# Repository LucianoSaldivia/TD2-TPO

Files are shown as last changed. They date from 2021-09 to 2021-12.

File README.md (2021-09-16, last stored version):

# TD2-TPO
 Proyecto Emulador de Chip8 para Técnicas Digitales 2

| Tarea | Responsable  | Estado |
|:---|:---:|:---:|
| Diseño PCB |  LL y Willy  | - |
| Diseño Carcaza | Fran | - |
| Pantalla | LL | - |
| SD | Luchos | - |
| Instrucciones | Fran, Luchos | + |
| Armado | LL | - |
| TDS y estructura | LS | T |
| Documentacion |  el guilardo | - |
| Interfaz seleccion juego | Luchos | - |

- Estados de Tareas:
  - "-"	-> Tarea en proceso
  - "+"	-> Tarea codeada, no testeada	
  - "T"	-> Tarea testeada, no integrada
  - "I"	-> Tarea integrada

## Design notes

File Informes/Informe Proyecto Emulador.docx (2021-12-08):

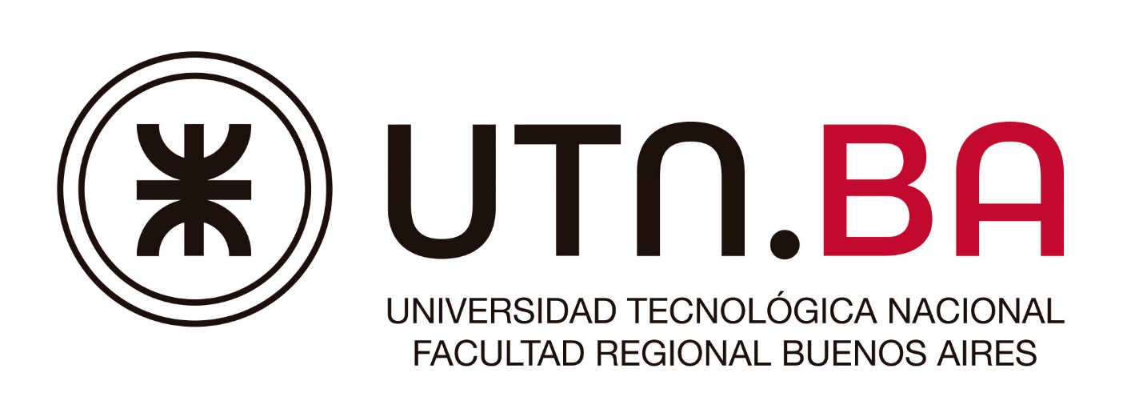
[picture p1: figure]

Técnicas Digitales II

Informe Técnico

Año 2021

Integrantes:

- Barreras Fauvety, Guillermo.

- Lopez, Luciano.

- Saldivia, Luciano.

- Stahl, Francisco.

Índice:

1. Descripción General.

1.1 Introducción.

1.2 Interfaz con el usuario.

1.3 Operación.

2. Hardware.

2.1 Diagrama en bloques.

2.2 Circuito esquemático.

2.3 Circuito Board.

2.4 Descripción del circuito.

2.5 Circuito impreso.

3. Software.

3.1 Entorno de desarrollo.

3.2 Sistema operativo.

3.3 Bibliotecas.

3.4 Programa principal.

3.5 Máquina de estados ¿?????

3.5 Rutinas de interrupción.

3.6 Rutinas generales.

4. Referencias.

1. Descripción General

1.1 Introducción

El proyecto trata sobre un emulador de chip 8. Es capaz de ejecutar ROMs desde una SD y ejecutarlas. Consta básicamente de dos dispositivos de entrada, una tarjeta SD por donde se cargarán las ROMs y un teclado matricial para ingresar los comandos por teclado, por último, un dispositivo de salida que será un display grafico monocromático de 128*64 pixeles.

Se emula el sistema completo, incluyendo stack pointer, registros de propósito general, memoria de video, memoria de teclado y set de instrucciones completo.

1.2 Interfaz con el usuario

El usuario tendrá como método de ingreso de información el teclado matricial, la bluepill será la encargada de interpretar qué teclas fueron presionadas y actuar en consecuencia. La presentación al usuario de la información procesada será a través del display hallado en la parte superior del dispositivo.

Además de las mencionadas interfaces, se encuentran en la parte inferior un switch de ON/OFF y un botón de reset.

1.3 Operación

La operación es sencilla, la interfaz de usuario también. A penas el equipo es alimentado, el directorio aparece en la pantalla. Con la tecla 2, el usuario recorrerá el directorio raíz y, por último, si quiere elegir una ROM simplemente debe oprimir el botón 5 y esperar a que la misma cargue. El dispositivo cuenta con un teclado matricial de 16 teclas (4x4) completamente funcionales mapeadas según la implementación original de chip 8. Las ROMs utilizan las teclas 2 (mover arriba), 4 (mover izquierda), 8 (mover abajo) y 6 (mover derecha) al igual que las flechas del teclado de la PC para jugar un juego).

2. Hardware

2.1 Diagrama en bloques

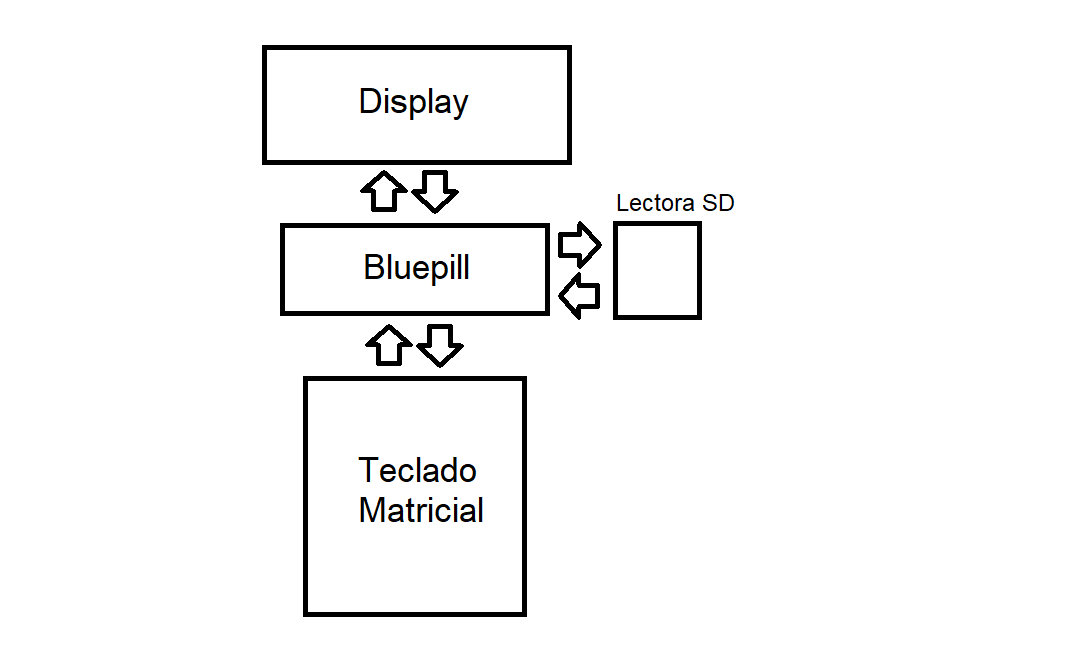
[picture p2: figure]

Tanto el display como la tarjeta SD utilizan el protocolo de comunicación SPI. El teclado matricial es controlado por una secuencia de barrido utilizando pines de propósito general.

2.2 Circuito esquemático

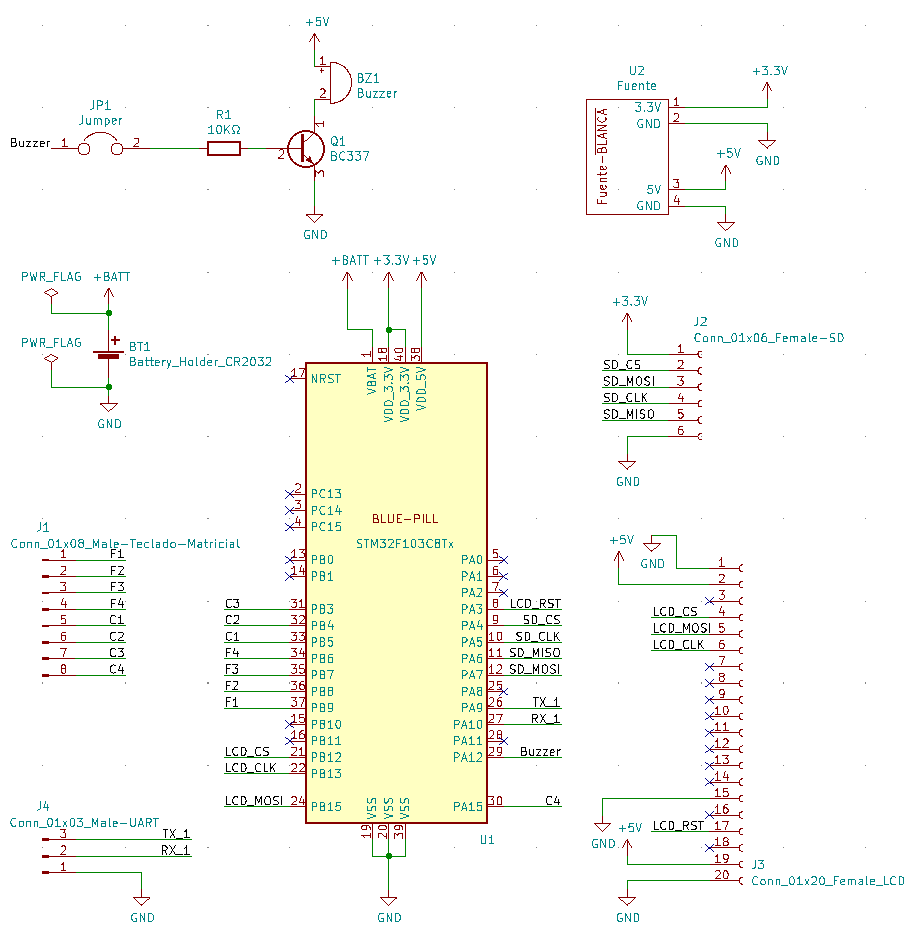
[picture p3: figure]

2.3 Circuito board

Sin plano de masa:

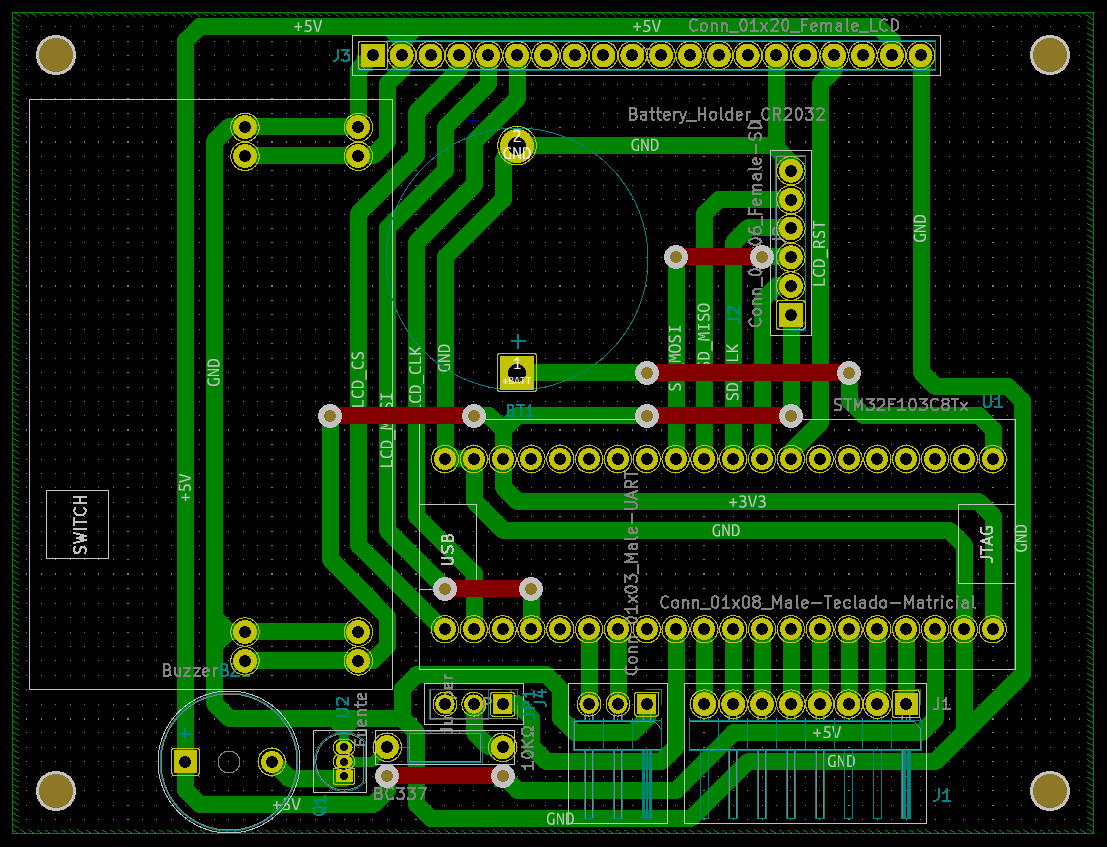
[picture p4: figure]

Con plano de masa:

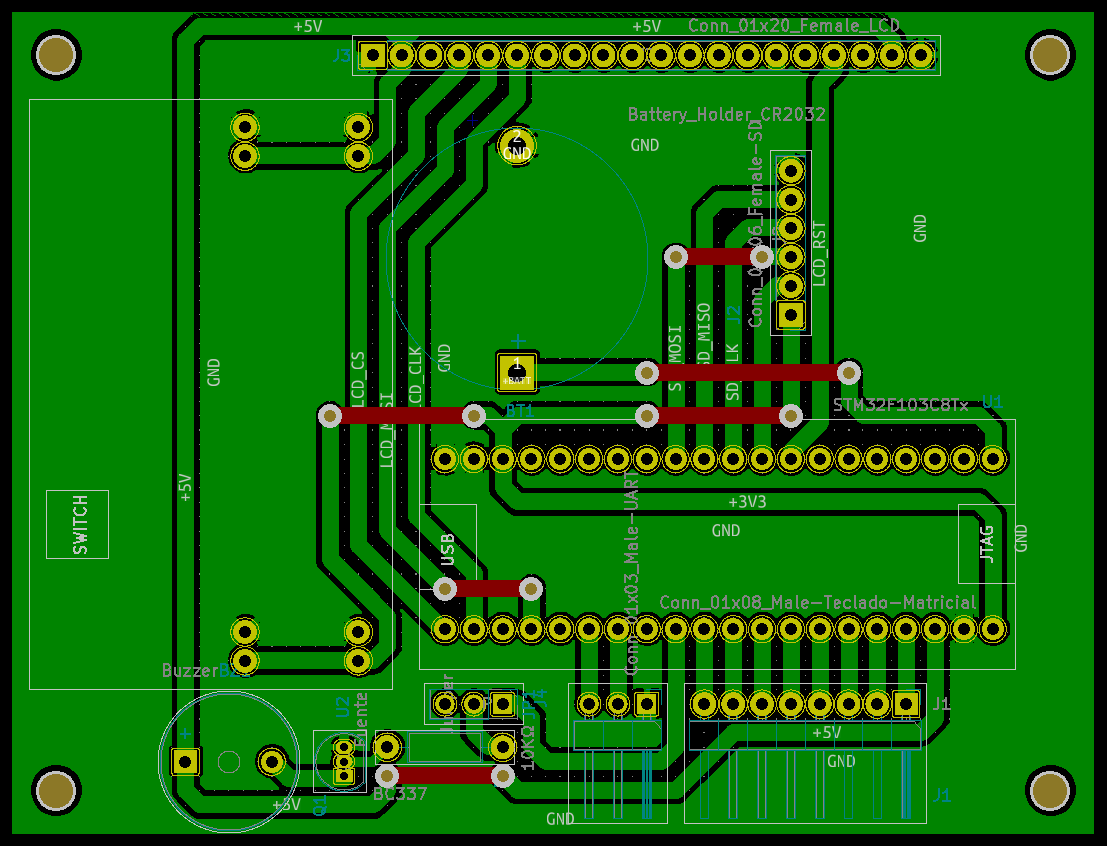
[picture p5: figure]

2.4 Descripción del circuito

El circuito consta de partes:

1. BLUEPILL: Microcontrolador principal.
2. Modulo SD: Placa secundaria conectada por una tira de pines a la placa principal.
3. PILA para RTC: Se utiliza para obtener un correcto funcionamiento de la librería FATFS al momento de escribir archivos para que luego tengan un correcto timestamp.
4. Conector teclado matricial y display: tira de pines hembra.
5. Regulador de tensión: Es la encargada de suministrar 5V y 3.3V para todos los componentes del proyecto.
6. Buzzer: Accionado a través de un transistor funcionando en conmutación, el mismo está configurado como emisor común. Se le colocó un jumper en serie con la resistencia de base para tener un mejor control del mismo y evitar sonidos molestos al momento de realizar pruebas.

2.5 Circuito impreso

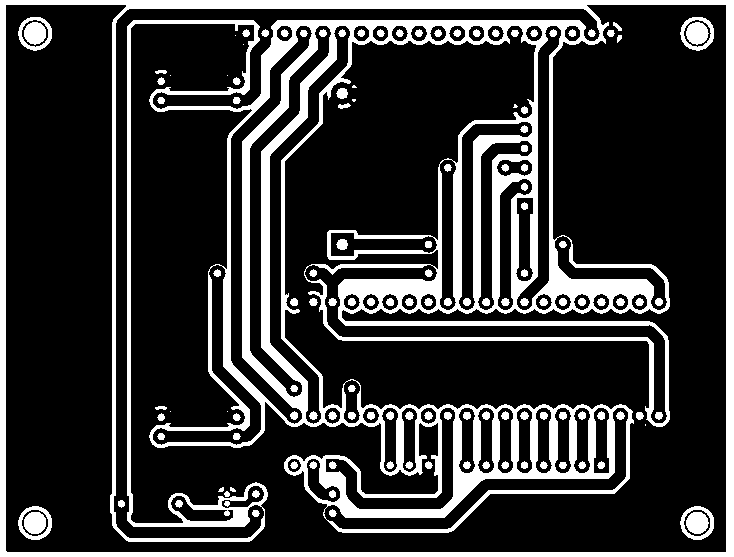
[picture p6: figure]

3. Software

3.1 Entorno de desarrollo: Se utilizo el IDE provisto por la catedra STM32Cube IDE. Para configurar el hardware se utilizó la herramienta de configuración de hardware para setear la mayoría de los periféricos.

3.2 Sistema operativo: Hay 3 tareas, de las cuales execute_instruction (wcet = 27 ms), es la que más carga impone al procesamiento del sistema, dado que, entre otras cosas, actualiza el display. Luego las otras tareas son actualizar_buzzer (wcet = 2 us) y process_user_input (wcet = 50 us).

Para hacer estas pruebas, se copiaron las tareas y se las adaptaron para ser incluidas en un scheduler, logrando así implementar la máquina de estado en un sistema TDS. Las primeras pruebas fueron hechas con un tick de sistema (o período secundario) de 10 ms, y era perceptible, en ciertos momentos, una falta de respuesta por parte del teclado (es decir que no se ejecutaba correctamente o a tiempo la tarea process_user_input), al tomar las entradas, en ciertas ocasiones se congelaba el display por un instante y luego continuaba, lo que mostraba que estábamos sobrecargando al scheduler con los tiempos de las tareas.

Repensando el análisis y las pruebas hechas, y conociendo el código, fue fácil darse cuenta de que el problema estaba en la variabilidad de la tarea execute_instruction, que, si bien en el peor caso tomaba unos 27 ms, la mayoría de las veces que esta tarea era ejecutada, el tiempo que tomaba era mucho menor, dado que solamente algunas veces la instrucción a ejecutar por el chip8 emulado era la de actualizar el display, y la mayoría de las veces eran instrucciones muchísimo más simples. Al haber medido esto, se observó que el tiempo de ejecución en cada tick (de los que vimos simulando) era de 1ms, 400 us, y lo más frecuente, menos de 20 us, pero la menos frecuente y más relevante era al actualizar el display. Por lo que se tenían dos soluciones posibles para lograr que este sistema funcione como TDS.

Una de las soluciones, sería modificar el programa, fraccionando el código de actualización del display en varias partes, lo suficientemente pequeñas para no sobrecargar la CPU en el tick de sistema, y que modificadas para puedan ser ejecutadas otras tareas entre dichas fracciones. Esto no sólo implicaría muchísimo cambio en el código, que a su vez complicaría al mismo, sino también implicaría alejarnos del chip8. Dado que el mismo no funcionaba como TDS, y dado que la intención del proyecto es emularlo tan cercano como sea posible, esta solución fue descartada.

La otra solución, era ampliar el tiempo de tick del sistema, dado que para 10 ms sobrecargábamos al procesador. Haciendo las cuentas en un Excel, se vio que el CPU estaba con una carga de 270%. Se agrandó el tick de sistema, usando un nuevo tick de 30 ms, para dar un margen sobre esos 27 ms de wcet medidos de la tarea execute_instruction. El problema era que al correr el programa con este nuevo tick, se trababa más seguido, las entradas se leían muy pocas veces, y cuando se leían, el programa se congelaba, tomando entre uno y dos segundos para continuar.

Concluimos entonces que el sistema no se puede planificar como TDS, a menos que se modifique como fue explicado, dado que por debajo de los 27 ms de tick de sistema, el sistema estaría sobrecargado, y por arriba de los 10 ms, el sistema tiene serios problemas para responder correctamente, dado que el mismo no está preparado para ser corrido como TDS.

3.3 Bibliotecas:

Se utilizaron cuatro bibliotecas:

- FATFS: Encarga del manejo de archivos.
- ST7920_SERIAL: Biblioteca adaptada a las necesidades del proyecto, encargada de la comunicación del display gráfico.
- TECLADO: Encargada de realizar el algoritmo de barrido, debounce y llenar un buffer con el valor de la tecla presionada.
- HAL: Encargada de manejar todos los periféricos del microcontrolador.

3.4 Programa principal:

El programa principal cuenta con 3 funciones de inicialización y carga de ROM en la memoria RAM. La función init_graphics(), es la encarga de inicializar el display gráfico, init_system(), es la encargada de poner a 0 todos los registros, memorias, teclado, STACK, TIMER de sonido y pantalla por último load_rom(), es la encargada de armar el menú mostrando el directorio en pantalla y seleccionar la ROM leída desde la tarjeta SD y cargarla en RAM.

Una vez pasada la inicialización, entramos en el while(1), que solamente tiene 3 funciones:

- process_user_input(): Lee el teclado matricial y si una tecla es presionada la pone en estado TRUE sino en estado FALSE.
- exec_instruction(): Se encarga de hacer las operaciones del core, es decir, fectch, decode y execute. La misma cuenta con dos máquinas de estado que serán descriptas más adelante.
- actualizar_buzzer(): Encargada de leer si el flag para activar o desactivar el buzzer está en ‘1’ o ‘0’. Prendiéndolo o apagándolo respectivamente.

La mayoría de las funciones tienen como parámetro la dirección de una estructura tipo Chip8 llamada user_chip8. La misma contiene todos los registros y flags de sistema necesarios para el funcionamiento del core.

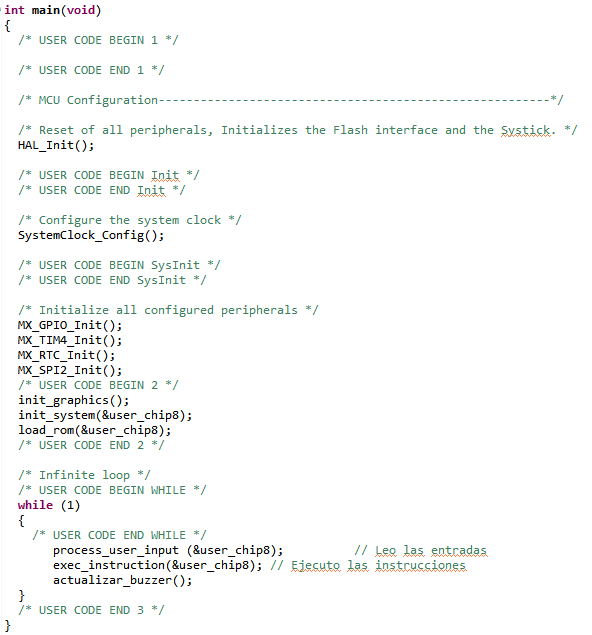
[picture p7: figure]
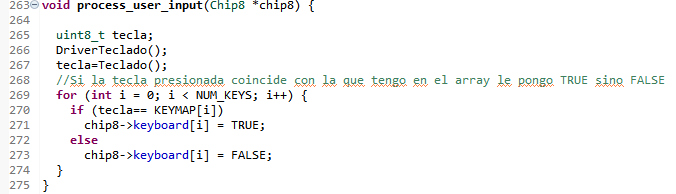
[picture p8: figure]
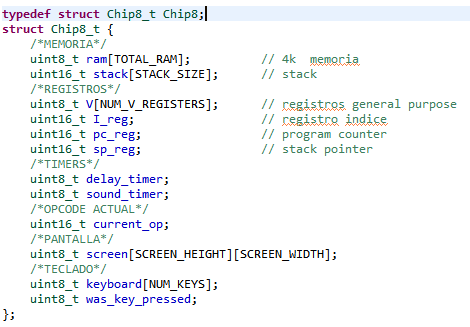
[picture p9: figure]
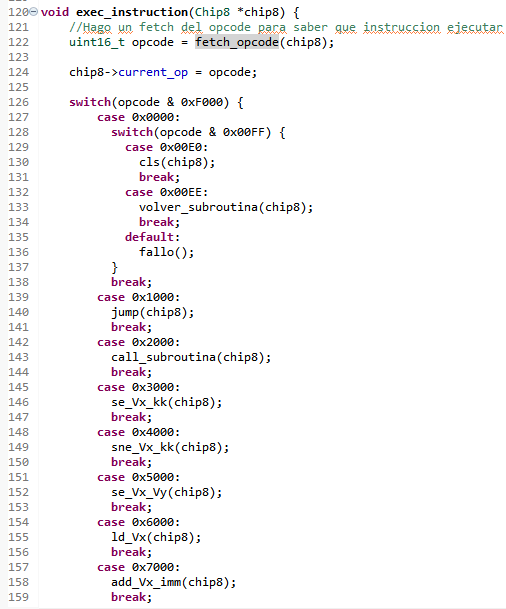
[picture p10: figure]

3.5 Máquina de estados:

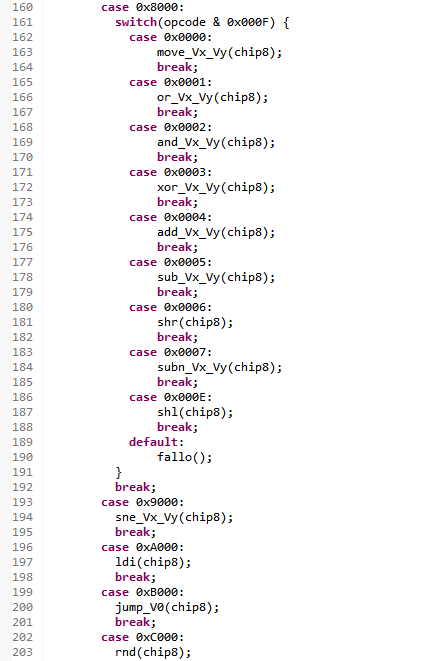
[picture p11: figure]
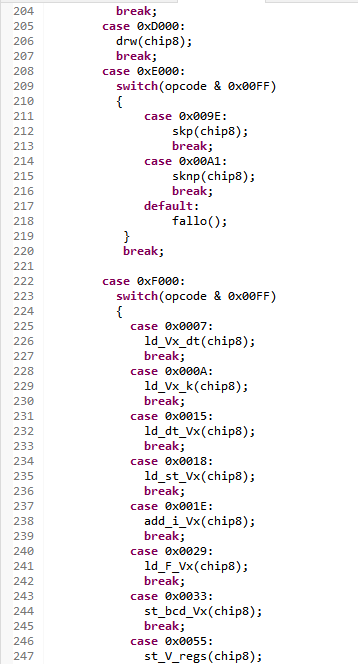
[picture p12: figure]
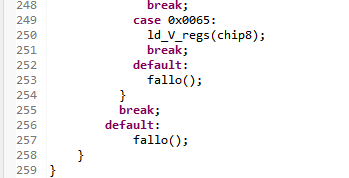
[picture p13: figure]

La función exec_instruction(), posee un switch a modo de máquina de encargado de decodificar el opcode actual. Los códigos de operación pueden ser encontrados fácilmente .

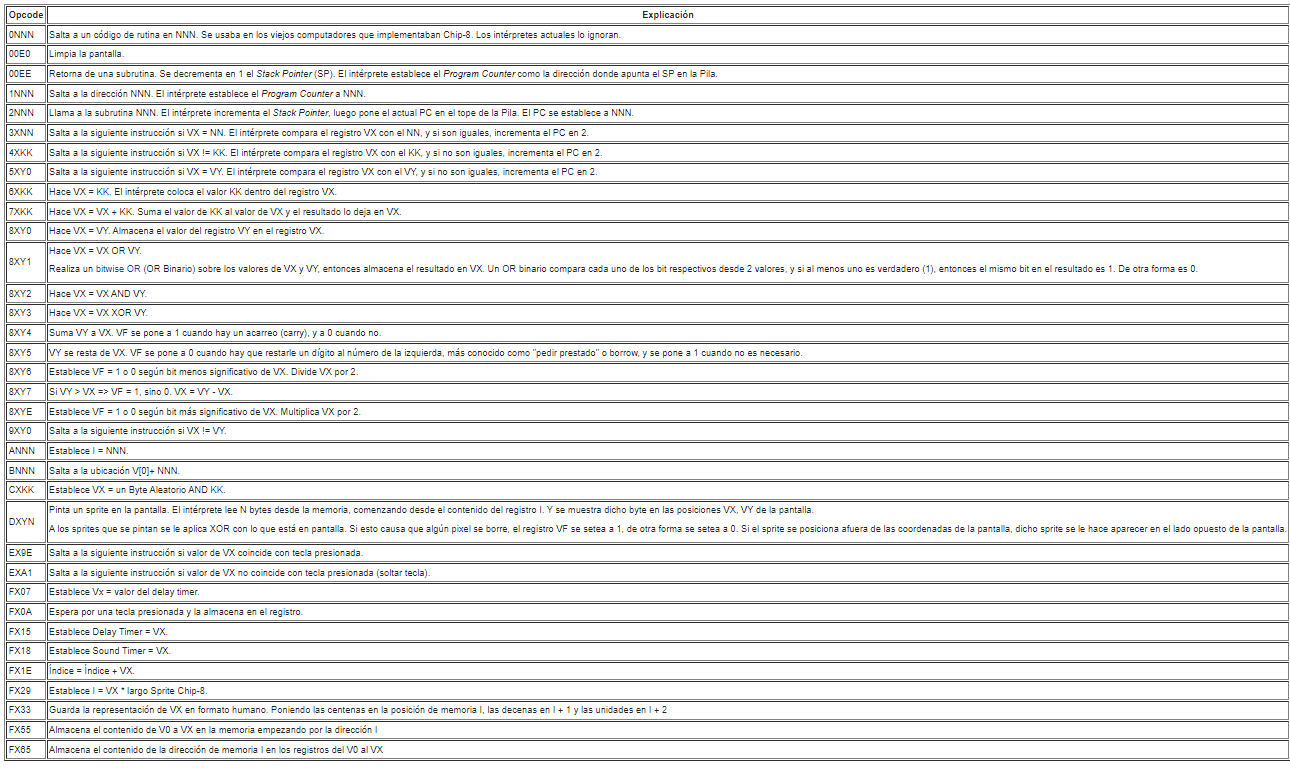
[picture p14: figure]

La función fetch_opcode(), es la encargada de buscar en RAM, (cargada previamente desde la SD) la parte alta y baja de la instrucción, componerla en una sola variable que luego será decodificada. Chip 8 utiliza instrucciones de 16 bits.

El switch principal es el encargado de recuperar los 4 bits más altos de la variable de 16 bits, para identificar el tipo de instrucción, luego según el tipo de instrucción se desglosa en distintos swichts tomando los 8 o 4 bits más pequeños decodificando por completo la instrucción.

3.5 Rutinas de interrupción:

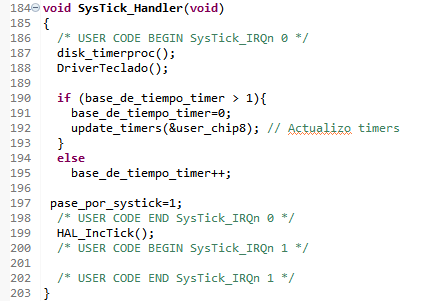
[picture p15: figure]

La única interrupción que es utilizada es la de Systick, la cual es llamada cada 1ms. En la misma se tienen coladas las interrupciones del timer de sonido y delay del chip8, lectura del teclado y rutinas de funcionamiento interno de la biblioteca FATFS para la lectura de la tarjeta SD.

3.6 Rutinas generales

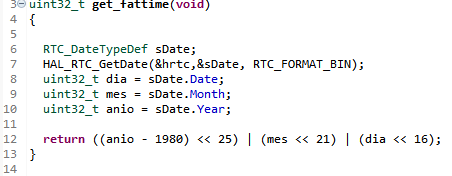
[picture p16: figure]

La rutina get_fattime(), esta implementada mediante un RTC alimentado a través de una pila CR2032 colocada en el PCB. De este modo cada vez que se escriba un archivo en la Bluepill el timestamp será el correcto.

En caso de que exista algún opcode no encontrado, automáticamente se imprimirá un código de error en la pantalla mediante la función fallo() a modo de alerta para el usuario. Esto se puede deber a un error en la ROM o en la SD.

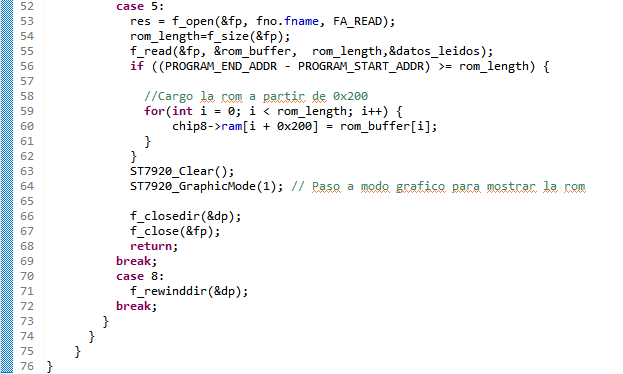
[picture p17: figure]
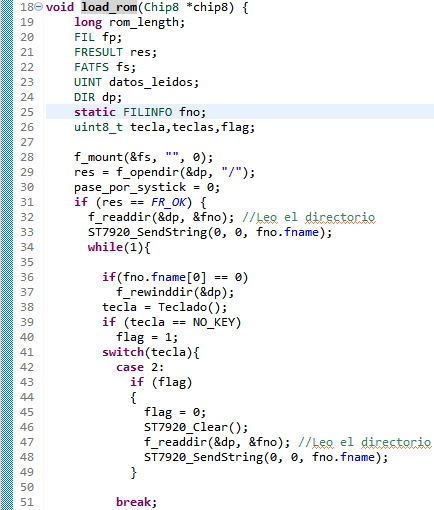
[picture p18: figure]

La función load_rom() como ya fue explicado anteriormente, es la encargada de leer el directorio y cargar la ROM en RAM. Como se puede ver en el código, utilizamos la biblioteca FATFS para hacer el manejo de archivos. Con el botón 2 incrementamos el índice del directorio y con el botón 5 cargamos la ROM.

4. Referencias

- https://es.wikipedia.org/wiki/CHIP-8.
- http://devernay.free.fr/hacks/chip8/C8TECH10.HTM.
- https://multigesture.net/articles/how-to-write-an-emulator-chip-8-interpreter/.
- https://en.bmstu.wiki/index.php?title=CHIP-8_(programming_language)&mobileaction=toggle_view_mobile.
- https://es.wikipedia.org/wiki/Sprite_(videojuegos).
- https://controllerstech.com/glcd-128x64-st7920-interfacing-with-stm32/.
- http://elm-chan.org/fsw/ff/doc/open.html.
- http://elm-chan.org/fsw/ff/doc/readdir.html.
- https://www.st.com/resource/en/user_manual/dm00105879-description-of-stm32f4-hal-and-ll-drivers-stmicroelectronics.pdf.
- https://tobiasvl.github.io/blog/write-a-chip-8-emulator.
- https://chip-8.github.io/links/.
- https://github.com/corax89/chip8-test-rom.
- https://www.zophar.net/pdroms/chip8/chip-8-games-pack.html.
- Diapositivas de clase Informática 2.
- Diapositivas de clase Técnicas Digitales 2.

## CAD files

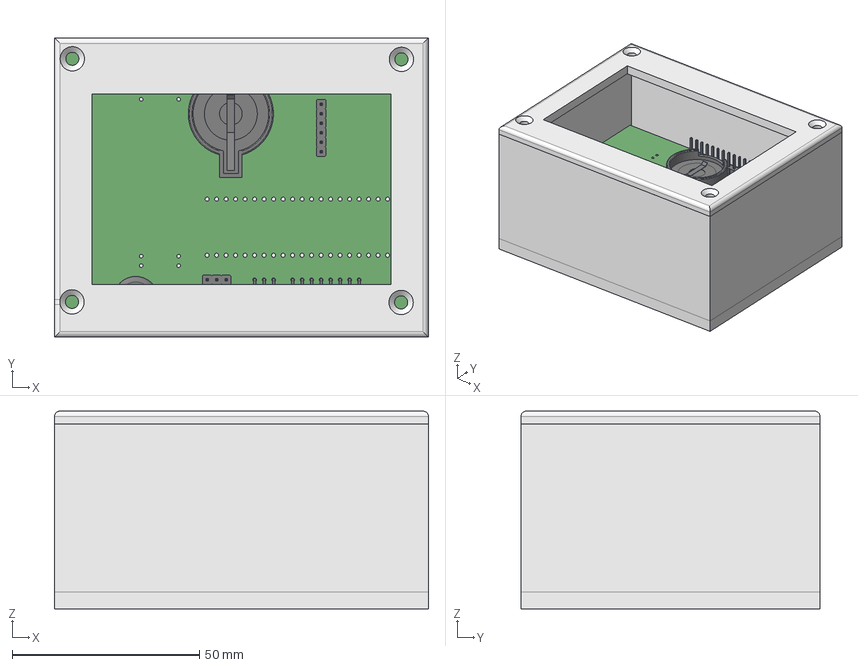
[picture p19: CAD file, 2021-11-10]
Gabinete/Gabinete.FCStd
100.0 x 80.0 x 52.9 mm
Tapa
Cuerpo

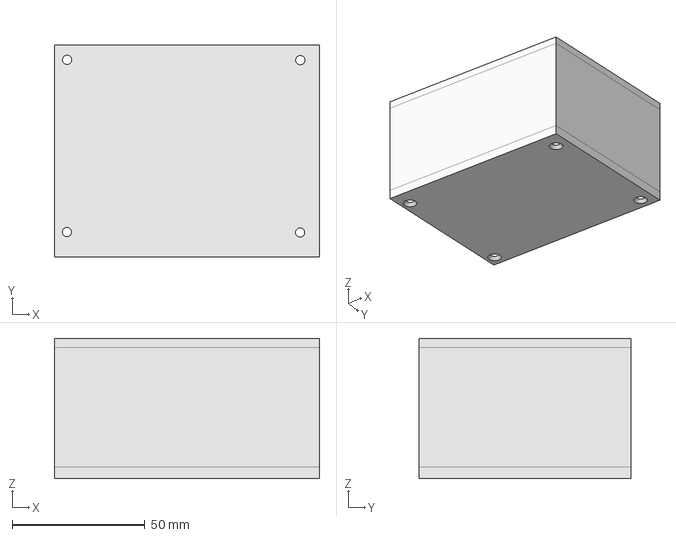
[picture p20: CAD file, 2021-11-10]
Gabinete/tapa.FCStd
100.0 x 80.0 x 53.0 mm

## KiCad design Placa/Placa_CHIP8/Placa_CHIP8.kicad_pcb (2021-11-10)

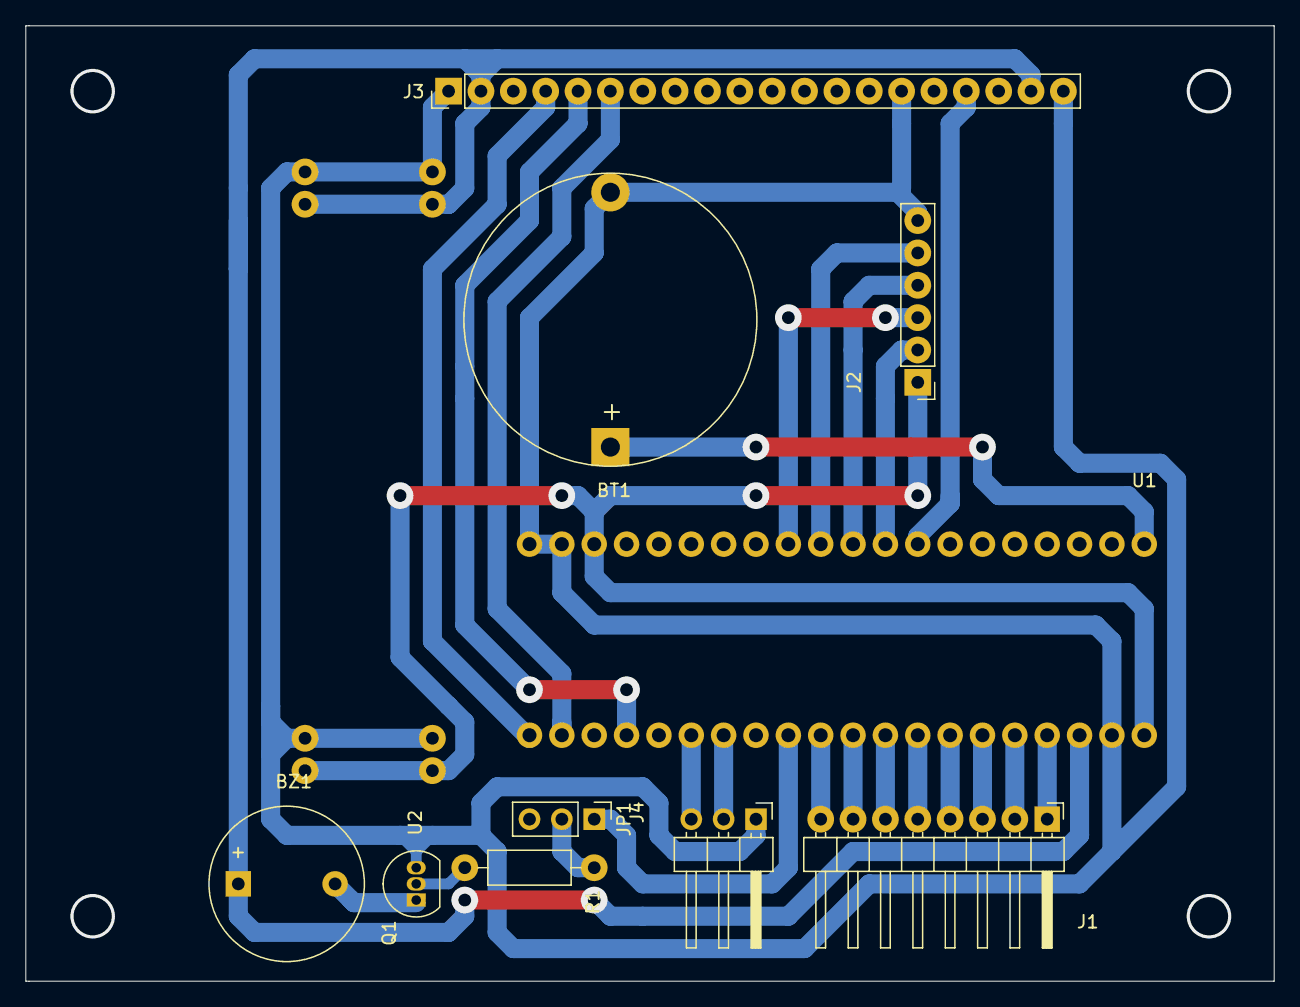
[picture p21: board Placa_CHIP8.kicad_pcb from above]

Board: 2 copper layers, 98.0 x 75.0 mm, 11 parts (0 on the bottom side), 26 nets.

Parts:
BT1: Battery_Holder_CR2032; BatteryHolder_Keystone_103_1x20mm
BZ1: Buzzer; Buzzer_12x9.5RM7.6
J1: Conn_01x08_Male-Teclado-Matricial; PinHeader_1x08_P2.54mm_Horizontal
J2: Conn_01x06_Female-SD; PinHeader_1x06_P2.54mm_Vertical
J3: Conn_01x20_Female_LCD; PinHeader_1x20_P2.54mm_Vertical
J4: Conn_01x03_Male-UART; PinHeader_1x03_P2.54mm_Horizontal
JP1: Jumper; PinHeader_1x03_P2.54mm_Vertical
Q1: BC337; TO-92_Inline
R1: 10KΩ; R_Axial_DIN0207_L6.3mm_D2.5mm_P10.16mm_Horizontal
U1: STM32F103C8Tx; Blue_Pill
U2: Fuente

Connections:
+3V3: J2.1, U1.18, U1.40, U2.1
+5V: BZ1.1, J3.2, J3.19, U1.38, U2.3
+BATT: BT1.1, U1.1
/Buzzer: JP1.1, U1.29
/C1: J1.5, U1.33
/C2: J1.6, U1.32
/C3: J1.7, U1.31
/C4: J1.8, U1.30
/F1: J1.1, U1.37
/F2: J1.2, U1.36
/F3: J1.3, U1.35
/F4: J1.4, U1.34
/LCD_CLK: J3.6, U1.22
/LCD_CS: J3.4, U1.21
/LCD_MOSI: J3.5, U1.24
/LCD_RST: J3.17, U1.8
/RX_1: J4.2, U1.27
/SD_CLK: J2.4, U1.10
/SD_CS: J2.2, U1.9
/SD_MISO: J2.5, U1.11
/SD_MOSI: J2.3, U1.12
/TX_1: J4.3, U1.26
GND: BT1.2, J2.6, J3.1, J3.15, J3.20, J4.1, Q1.3, U1.19, U1.20, U1.39, U2.2, U2.4
unnamed: BZ1.2, Q1.1
unnamed: JP1.2, R1.2
unnamed: Q1.2, R1.1

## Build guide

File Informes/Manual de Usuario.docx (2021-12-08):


Técnicas Digitales II

Manual de Usuario

Año 2021

Integrantes:

- Barreras Fauvety, Guillermo.

- Lopez, Luciano.

- Saldivia, Luciano.

- Stahl, Francisco.

Índice:

1. Descripción General.

2. Alimentación.

2.1 Tensiones de trabajo.

2.2 Conexionado.

3. Funcionamiento.

3.1 Identificación de componentes.

3.2 Encendido y apagado.

3.3 Selección de juego.

4. Precauciones.

5. Contenido de la caja.

6. Soporte técnico.

1. Descripción General

¡Felicidades! Usted es ahora poseedor de uno de nuestros más modernos dispositivos de entretenimiento. Con él podrá revivir los juegos de su infancia y recordar esos tantos buenos momentos que con el pasar del tiempo fueron quedando olvidados en el pasado. El emulador de Chip-8 le dará la posibilidad de jugar nuevamente a los clásicos que corrían sobre él y en calidad original. Se le garantiza una experiencia 100% nativa en tanto calidad gráfica y rendimiento. Una consola de años, pero traída a la actualidad con componentes modernos.

2. Alimentación

2.1. Tensiones de trabajo

Tensión: 100V-250V.

Frecuencia: 50-60Hz.

Potencia: 1W.

2.2. Conexionado

El equipo cuenta con un conexionado sencillo de realizar. Sólo se deberá conectar el transformador al suministro eléctrico del hogar y el extremo opuesto del cable deberá insertarse en el puerto de ubicado a un lado del dispositivo.

3. Funcionamiento

3.1 Identificación de componentes

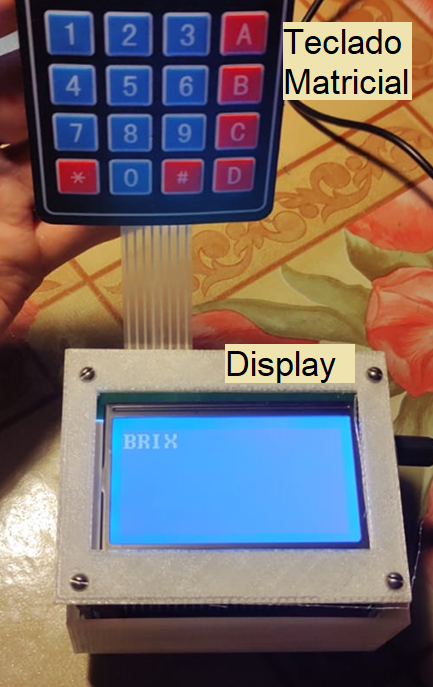
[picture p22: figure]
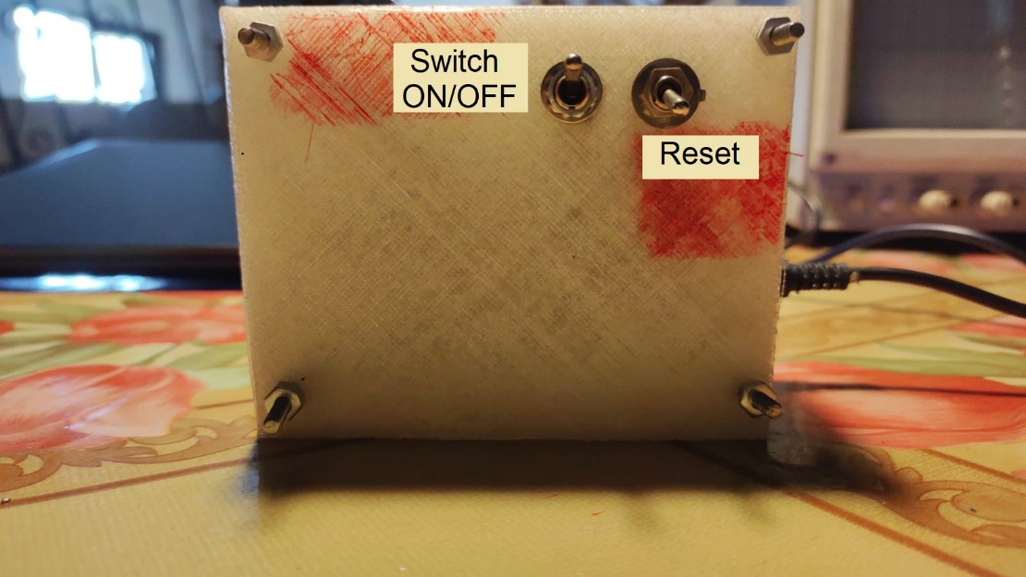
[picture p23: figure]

3.2 Encendido y apagado

Una vez que el dispositivo se encuentre conectado al suministro eléctrico del hogar ya podrá encenderlo moviendo el switch de ON/OFF que se encuentra en la parte inferior del equipo.

Tras accionar esté contacto, habrá prendido el emulador y podrá visualizar en el display la primera opción del listado de aplicaciones precargadas con las que cuenta.

3.3 Selección de juego

Llegado a este punto se procederá a desplazarse por los ítems del menú utilizando las teclas de navegación del teclado matricial hasta hallar la aplicación que se desea ejecutar. Una vez encontrada la misma, deberá presionar la tecla de acción (tecla 5) para poder acceder.

Cada aplicación tiene sus controles particulares, todas son completamente intuitivas y se basan principalmente en las teclas de navegación tal y como las expone la imagen.

En caso de desear salir de la aplicación en la que se encuentre para luego entrar en otra, se podrá presionar el botón de reset. Tras presionarlo el sistema se reiniciará y será llevado nuevamente al menú de inicio.

4. Precauciones

- El dispositivo no es sumergible y es susceptible a rayaduras.
- En caso de requerir limpiarlo se deberá utilizarse un paño apenas humedecido.
- No dejar caer.
- No exponer al sol durante tiempo prolongado.
- No exponer a ambientes con gran concentración de partículas en el aire.

5. Contenido de la caja

- 1x Emulador Chip-8.

- 1x Transformador de Alimentación.

6. Soporte técnico

Nuestro service autorizado Cristian de Lugano. Contacto: 1133862235.

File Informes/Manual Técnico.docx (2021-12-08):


Técnicas Digitales II

Manual Técnico

Año 2021

Integrantes:

- Barreras Fauvety, Guillermo.

- Lopez, Luciano.

- Saldivia, Luciano.

- Stahl, Francisco.

Índice:

1. Descripción General.

2. Herramientas necesarias.

2.1 Instrumental.

2.2 Listado de componentes.

3. Consideraciones de seguridad

4. Diagramas.

4.1. Diagrama en bloques.

4.2. Esquemático.

4.3. Board.

4.3.1. Distribución de componentes.

4.3.2. Pistas y puntos relevantes.

5. Soluciones de problemas.

6. Soporte técnico.

1. Descripción General

En este manual encontrará todo lo necesario para poder solucionar los diversos problemas que podría llegar a tener el dispositivo en cuestión.

Se trata de un juego de mano que comprende un emulador para ROMs interpretadas por CHIP-8

Su función es leer ROMs previamente cargadas en una memoria microSD ubicada dentro del dispositivo y representarlas de forma gráfica mediante el display. El usuario podrá interactuar con el sistema únicamente mediante el teclado matricial.

2. Herramientas necesarias

2.1. Instrumental

Los materiales necesarios con los que deberá contar para resolver cualquier eventualidad serán:

- Destornilladores.

- Tester.

- Osciloscopio.

2.2. Listado de componentes

A continuación, se detalla el listado de componentes fundamentales utilizados en la fabricación del dispositivo junto a sus respectivos modelos para el caso en el que se deba reemplazar alguno.

- Bluepill.

- Display grafico 128*64.

- Teclado matricial.

- Modulo Lector de tarjetas SD.

- Transformador de entrada 220VAC – 12 VCC.

3. Consideraciones de seguridad

A la hora de manipular este dispositivo se recomienda ante todo desarmar y quitar la carcasa para poder trabajar cómodamente sobre la plaqueta sin tener que tomar precauciones en tanto al cuidado del aspecto físico exterior del producto. Fue diseñado de forma tal que esto sea fácilmente conseguible.

Será importante realizar las mediciones necesarias en un área de trabajo limpia, ya que, como con cualquier dispositivo electrónico, existirá la posibilidad de crearse un corto si entraran partículas de material conductor en él.

4. Diagramas

4.1. Diagrama en bloques


4.2. Esquemático


4.3.1. Board - Distribución de componentes

Sin plano de masa:


Con plano de masa:


4.3.2. Board - Pistas y puntos relevantes

Pista GND:

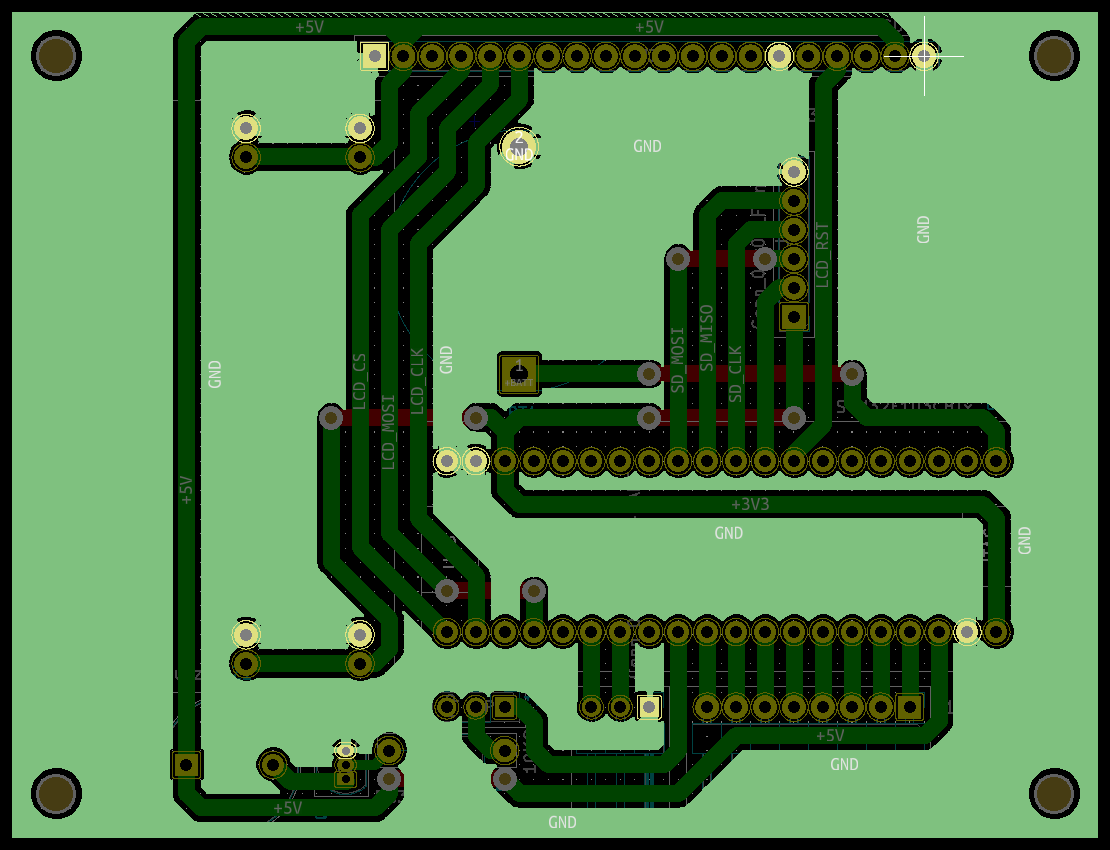
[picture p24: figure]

Pista 5 V:

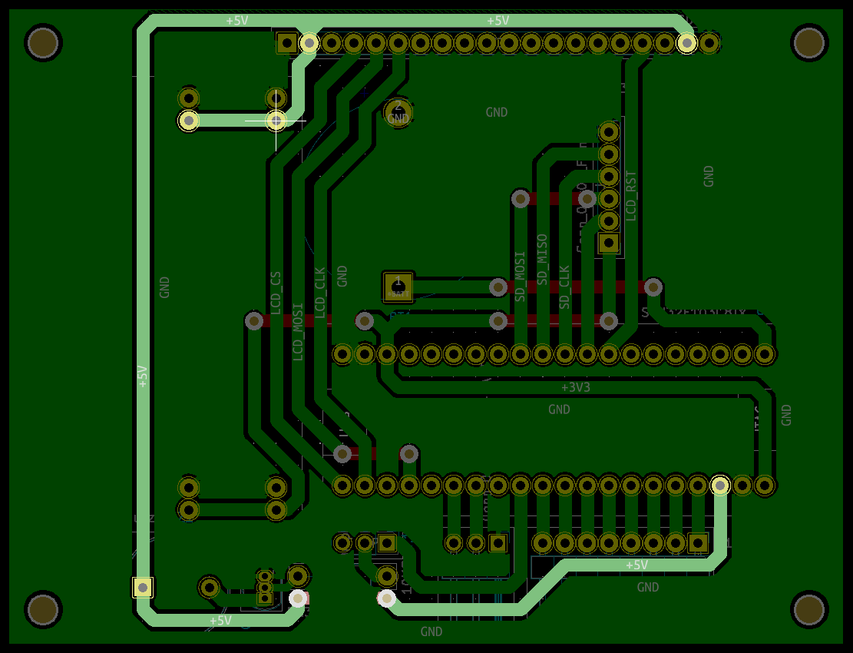
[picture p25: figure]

Pista 3,3 V:

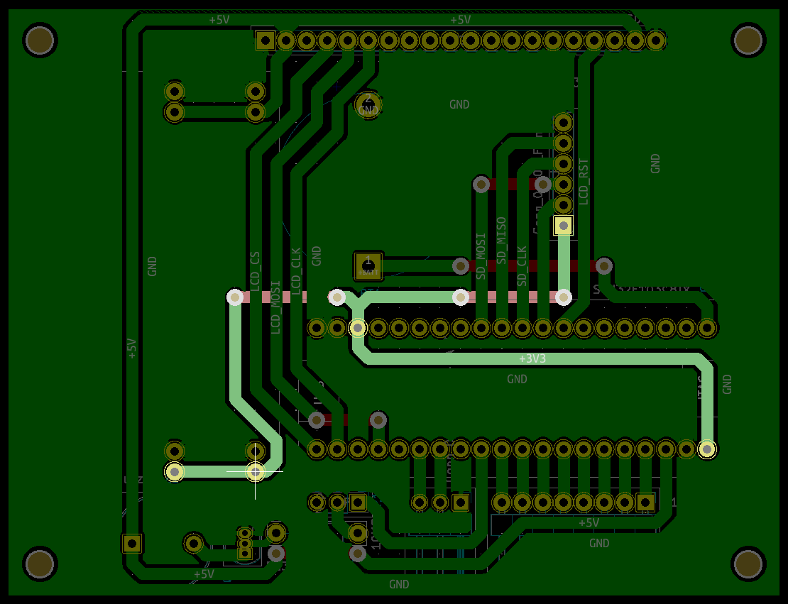
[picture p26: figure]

5. Soluciones de problemas

Si el dispositivo no enciende se deberá:

- Probar continuidad en el cable de alimentación para descartar que en él se halle el problema.
- Verificar puntos de alimentación de la placa. Para ello se podrá ayudar con los diseños en Board detallados en el punto anterior.
- Desconectar la alimentación y analizar la existencia de continuidad en las pistas correspondientes para así descubrir si existe algún tipo de cortocircuito o pista cortada.

En caso de no visualizarse el menú principal en el display tras encender el quipo:

- Probar el display en una placa de prueba para descartar la posibilidad de que este se encontrase averiado.
- Conectar un osciloscopio en las líneas de SPI para verificar que se estén enviando datos tanto en el módulo SD como en el display.
- Verificar que la SD abra en una PC y se pueda leer el contenido.

En caso de no funcionar el teclado matricial:

- Medir entradas y salidas del mismo para saber si se está realizando el barrido correspondiente para la captura de información.
- Verificar con el osciloscopio que ese encuentre en funcionamiento el oscilador del microcontrolador.

En caso de falla de la SD:

- Volver a escribir desde una PC las ROMs en la tarjeta.
- Reemplazarla.

6. Soporte técnico

Nuestro service autorizado Cristian de Lugano. Contacto: 1133862235.

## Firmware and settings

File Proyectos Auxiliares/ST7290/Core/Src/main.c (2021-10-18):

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

/* Includes ------------------------------------------------------------------*/
#include "main.h"

/* USER CODE BEGIN Includes */
#include "ST7920_SERIAL.h"
#include "delay.h"
/* USER CODE END Includes */

SPI_HandleTypeDef hspi2;

TIM_HandleTypeDef htim4;

void SystemClock_Config(void);
static void MX_GPIO_Init(void);
static void MX_TIM4_Init(void);
static void MX_SPI2_Init(void);
/**
  * @brief  The application entry point.
  * @retval int
  */
int main(void)
{
  /* MCU Configuration--------------------------------------------------------*/

  /* Reset of all peripherals, Initializes the Flash interface and the Systick. */
  HAL_Init();

  /* Configure the system clock */
  SystemClock_Config();

  /* Initialize all configured peripherals */
  MX_GPIO_Init();
  MX_TIM4_Init();
  MX_SPI2_Init();
  /* USER CODE BEGIN 2 */
  delay_init();
	ST7920_Init(&hspi2, GPIOB, GPIO_PIN_12);
  /* USER CODE END 2 */

  /* Infinite loop */
  /* USER CODE BEGIN WHILE */
  while (1)
  {
    /* USER CODE END WHILE */

		/* USER CODE BEGIN 3 */
		ST7920_SendString(0,0, "HELLO WORLD");
		ST7920_SendString(1,0, "FROM");
		ST7920_SendString(2,0, "CONTROLLERSTECH");
		ST7920_SendString(3,0, "1234567890!@#$%^");

		HAL_Delay(2000);
  }
  /* USER CODE END 3 */
}

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


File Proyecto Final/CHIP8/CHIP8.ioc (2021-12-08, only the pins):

Mcu.UserName=STM32F103C8Tx
PA0-WKUP.Signal=GPIO_Output
PA1.Signal=GPIO_Output
PA12.GPIO_Label=BUZZER
PA12.Signal=GPIO_Output
PA13.Signal=SYS_JTMS-SWDIO
PA14.Signal=SYS_JTCK-SWCLK
PA15.Signal=GPIO_Output
PA2.Signal=GPIO_Output
PA3.Signal=GPIO_Output
PB12.Signal=GPIO_Output
PB13.Signal=SPI2_SCK
PB15.Signal=SPI2_MOSI
PB3.Signal=GPIO_Output
PB4.Signal=GPIO_Output
PB5.Signal=GPIO_Output
PB6.Signal=GPIO_Input
PB7.Signal=GPIO_Input
PB8.Signal=GPIO_Input
PB9.Signal=GPIO_Input
PC14-OSC32_IN.Signal=RCC_OSC32_IN
PC15-OSC32_OUT.Signal=RCC_OSC32_OUT
PD0-OSC_IN.Signal=RCC_OSC_IN
PD1-OSC_OUT.Signal=RCC_OSC_OUT

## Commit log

2021-09-07 Scheduler Testeado con dos tareas de ejemplo
    Se configuran las tareas con Período (en Ciclos Secundarios) y Offset (en micro segundos).
    Las tareas deben tener como parámetro void*, ejemplo:
    <task_type> <task_name>( void *p );
2021-09-15 CHIP8 e instrucciones
    Implementacion de la estructura del CHIP8 y las instrucciones asociadas al mismo
2021-09-15 Estados de tareas
2021-09-15 Estado de Tareas -> Formato
2021-09-16 LCD GRAFICO & SD
    LCD grafico andando bien
    SD compila ok falta probar con una sd porque no tengo todavia
    Hay que cambiar SPI1 a SPI2
    Verificar TDS
2021-09-20 Agrego LCD Grafico, Teclado matricial y SD
    LCD GRAFICO OK -> Funcionando TIM4
    TECLADO MATRICIAL OK
    SD-> Resolviendo mis problemas con alarcon
    [SD.ioc, ST7920_SERIAL.c, delay.c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]
2021-09-20 Cambio de lugar algunas cosas
2021-09-23 Agrego Intento de CHIP8
2021-09-23 Terminar de resolver tema pantalla
    [main.c]
2021-09-23 Graficar()->Andando
    Habría que probarla con una rom posta
2021-10-06 graficando y leyendo de la SD
2021-10-06 Agrego placa - Lucho L & incios del gabinete
    [Gabinete.FCStd, Placa_CHIP8.kicad_pcb, Placa_CHIP8.sch]
2021-10-07 Corriendo space invaders en resolucion nativa.
    Hay que mejorar la entrada de datos
    Resolucion de pantalla
2021-10-18 SPI por HWD display
2021-10-21 Modifico Placa con las conexiones nuevas
    [Placa_CHIP8.kicad_pcb, Placa_CHIP8.sch]
2021-10-31 Agrego modelo Willy funcando ok y V1 gabinete
    [Gabinete.FCStd, Placa_CHIP8.kicad_pcb, Placa_CHIP8.sch]
2021-11-10 Mejoras minimas codigo
    [Gabinete.FCStd, Placa_CHIP8.kicad_pcb, tapa.FCStd]
2021-11-23 Cambios menores en el codigo

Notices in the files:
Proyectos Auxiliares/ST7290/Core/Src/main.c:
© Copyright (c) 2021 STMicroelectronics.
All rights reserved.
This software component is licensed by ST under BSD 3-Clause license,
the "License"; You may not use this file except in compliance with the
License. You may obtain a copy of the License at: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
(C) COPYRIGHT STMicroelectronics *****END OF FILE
